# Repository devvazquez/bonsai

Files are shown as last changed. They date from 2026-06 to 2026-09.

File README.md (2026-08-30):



The main repository containing all the files involved in the creation of this smart device, such as cad files, code, designs...

## Motivation for the project
I've always wanted to do a hardware project like this, involving a camera. And I love the idea of being able to connect AI with real-world data, so this project is perfect!

## Repository Structure

```
Bonsai-Glasses/
├── bom.csv             # The bill of materials with links.
├── src/
│   ├── firmware/       # Embedded / microcontroller source code
├── hardware/
│   ├── cad/            # 3D CAD models and mechanical designs
│   └── bonsai_pcb/     # PCB schematics and board layouts
└── assets/             # Images, logos, and other design assets
```

## How it works (WIP)
Thanks to the [backend](https://github.com/devvazquez/bonsai-backend), Bonsai is able to interact easily with **free and fast** AI providers, such as Groq (for the STT and vision LLM). For TTS, it uses Piper (locally), which is esential for **Catalan** support. 
Thanks to the board, a XIAO ESP32 Sense, we can use the provided camera to give the model visual context, which is then used to describe the current enviroment.
Using the built-in web server in the firmware, you can configre all the Wifi networks, and default user button actions. You can also change parameters such as default language. Some of these parameters can also be configured using the wake word (ex. "Hey Bonsai, change the language to Spanish"). 

## Flashing a board
The [web flasher](https://devvazquez.github.io/bonsai/) writes a firmware release to a board over USB from the browser, with no toolchain to install. Plug the board in, pick a version and press write. It needs Chrome, Edge or Opera on a computer, since it runs on the Web Serial API.

Releases are cut by hand: run the **Build and publish firmware** workflow from the Actions tab, give it a version like `v1.0.0`, and it builds the firmware, tags the commit and publishes the release the page reads (`.github/workflows/release.yml`). The page itself lives in [`docs/`](docs/) and is described in [`docs/README.md`](docs/README.md).

Your settings are safe across a flash: `/config.json`, the saved networks and the voice clips are on the SD card, and only the firmware images get replaced.

## Bill of Materials
| Name | Purpose | Quantity | Total Cost (USD) | Link | Distributor |
| --- | --- | --- | --- | --- | --- |
| 3.7V Lipo Battery | Powering the device. | | $10.50 | [Buy](https://www.aliexpress.us/item/3256808990377891.html) | Aliexpress |
| JST PH 2.0 Connector | Connect battery to PCB (Bent pin socket, 2P) | | $1.95 | [Buy](https://www.aliexpress.us/item/3256807255498839.html) | Aliexpress |
| Seeed Studio XIAO ESP32S3 Sense | Tiny devboard with camera support (ESP32S3 Sense Module) | | $20.00 | [Buy](https://es.aliexpress.com/item/1005005544221475.html) | Aliexpress |
| MAX98357A I2S Audio Amplifier | Drives the speakers since ESP32 lacks enough power directly | | $1.68 | [Buy](https://www.aliexpress.us/item/3256812158409627.html) | Aliexpress |
| 75MM OV3660 120° Camera | Captures image for ESP32 to process (120 Degrees GOOD) | | $6.89 | [Buy](https://es.aliexpress.com/item/1005009339247009.html) | Aliexpress |
| Push Button | Taking the photo | | 2.95$ | [Buy](https://www.aliexpress.us/item/3256804762387991.html) | Aliexpress |
| Small Speaker | Playing the TTS sound | | 4.53$ | [Buy](https://www.aliexpress.us/item/3256811556916339.html) | Aliexpress |
| PCB | Holding all the components together | | 23$ | [Buy](https://jlcpcb.com/) | JLPCB |

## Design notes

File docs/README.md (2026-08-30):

# The flashing page

`docs/` is the site published at <https://devvazquez.github.io/bonsai/>. It
writes a firmware release to a board over USB from the browser, using the Web
Serial API and [esptool-js](https://github.com/espressif/esptool-js) (vendored
under `vendor/esptool-js/`, version in `vendor/esptool-js/VERSION`).

Nothing runs on a server: the release assets are fetched from GitHub by the
browser and pushed straight down the serial port.

## Design

The page borrows its tokens and components from the firmware's own setup portal
(`src/firmware/bonsai-firmware/bonsai-setup.html`): the same off-white ground,
the same step rail, buttons, summary rows and status tints, and the same logo
asset. Flashing a board and setting it up afterwards should not look like two
different products, so when that page's palette changes, `styles.css` follows
it.

## Where the images go

`.github/workflows/release.yml` attaches a `manifest.json` to every release it
publishes and the page reads it, so the offsets come from the build rather than
from guessing. That workflow only runs when someone starts it from the Actions
tab with a version number, so tags and pushes never publish a release on their
own.
Releases assembled some other way still work; the page falls back to, in order:

1. **`manifest.json`** in the [ESP Web Tools](https://esphome.github.io/esp-web-tools/)
   shape. Paths resolve against the release's download URL, so plain file names
   are enough.
2. **A merged image**, one asset whose name contains `merged`, `combined`,
   `factory` or `full`, written at `0x0`.
3. **The PlatformIO set**: `bootloader.bin` (`0x0`), `partitions.bin`
   (`0x8000`), `boot_app0.bin` (`0xe000`), `firmware.bin` (`0x10000`).

Whichever route is taken, the page lists every image and its offset before it
writes anything.

Draft releases are hidden. Pre-releases are listed and marked, and the newest
stable release is the one preselected.

## What flashing does not touch

The board keeps its settings. `/config.json`, the Wi-Fi list and the voice clips
live on the SD card, and nothing here writes to the card. Only the firmware
images are replaced, so a board that was already set up comes back on the
network by itself.

## Enabling the site

The workflow in `.github/workflows/pages.yml` publishes this directory on every
push to `main`, but Pages has to be switched on once by a person: **Settings,
Pages, Build and deployment, Source: GitHub Actions**. The workflow cannot do
it for you, since its token is not allowed to create the site. Until that
setting is flipped the deploy job fails at `configure-pages`; re-run it
afterwards and the site goes up.

## Local preview

Web Serial needs a secure context, which `localhost` counts as:

```sh
python3 -m http.server -d docs 8000   # then open http://localhost:8000
```

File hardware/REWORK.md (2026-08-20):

# Board rework: the microSD bus

The XIAO ESP32-S3 **Sense** puts its microSD slot on the same pads the header
brings out, and the first Bonsai board hands two of them to something else:

| Net | U1 pad | GPIO | XIAO alias | Also used by the microSD as |
| --- | --- | ---- | --- | --- |
| `BT1` (SW1 pad 1) | 11 | GPIO9 | D10 | **MOSI** |
| `SD` (U2 pad 4, MAX98357A shutdown) | 10 | GPIO8 | D9 | **MISO** |

The slot's other two lines are SCK on GPIO7 (D8) and CS on GPIO21, which nothing
else touches.

## What it looked like

Flash the board, configure the WiFi over the AP, reboot — and every operation on
the card fails. `SD.begin()` itself succeeds, because at that point nothing has
touched the bus yet; `Audio::begin()` ran next and drove GPIO8 low to hold the
amplifier off. From there `/config.json` cannot be read or written, `/audio`
cannot be created, and the credentials entered over the AP are lost on every
boot, so each one looks like the first.

## The fix

**Firmware — ownership of GPIO8, not its level.** `SPI.begin()` routes that pad
to the SPI peripheral's MISO input. Any `pinMode()` on it points it back at
plain GPIO and the peripheral is left reading a disconnected input — and that is
true of `INPUT` and `INPUT_PULLUP` exactly as much as of `OUTPUT`. The card
still mounts, because identification is short and forgiving, and then every
transfer comes back empty. So nothing outside `playWav()` touches the pin, and
`playWav()` only takes it once the clip is in PSRAM and the file is closed,
then hands it straight back with `spiAttachMISO()`.

Between clips the pin stays with the SPI peripheral and `SD_MODE` is held at
ground by its own internal 100k pull-down, which shuts the amplifier down for
free. That works because this is the bare MAX98357A and not a breakout, whose
100k to VDD would instead have left it on.

**No second rework is needed, and no pull-up.** Two things that look like the
cause here are not:

- *The 100k pull-down on `SD_MODE` dragging MISO down.* It does sit on the net,
  and the arithmetic is unflattering — against the chip's ~45k internal pull-up
  it divides to 2.28 V, under the 2.475 V an ESP32-S3 wants for a HIGH. It still
  is not the fault: with the pin left alone the bus runs fine at full speed.
  Adding a 10k to 3V3 on D9 fixes nothing that is broken.
- *The bus clock being too fast.* A card that mounts and then fails every
  transfer is the classic picture of an over-fast clock, because mounting
  happens at the 400 kHz the spec mandates for identification. Dropping to
  400 kHz changes nothing here; the board reads and writes happily at 4 MHz.

**PCB — the button.** Cut the `BT1` trace between SW1 pad 1 and U1 pad 11
(GPIO9/MOSI) and run a wire from SW1 pad 1 to **U1 pad 4 — GPIO4, D3**, the
nearest pad nothing else claims. SW1 pad 2 already goes to GND, so the switch
stays active-low against the internal pull-up and `BUTTON_PIN` is 4.

Do the cut on the U1 side of SW1 pad 1 so the pad keeps its own copper, and
check continuity between SW1 pad 1 and U1 pad 11 afterwards — it should read
open.

## Pads still free on the header

D4 (GPIO5/SDA), D5 (GPIO6/SCL), D6 (GPIO43/TX), D7 (GPIO44/RX).

## For the next revision

Route `BT1` to GPIO4 in the schematic so the board needs no rework. Giving the
amplifier's `SD` net its own free pad — D4 (GPIO5) — would also let the firmware
stream a clip straight off the card again instead of buffering it into PSRAM
first, and would drop the `spiAttachMISO()` dance in `Audio::ampRelease()`
along with the standing risk that some future code path calls `pinMode()` on
GPIO8 and quietly breaks the card all over again.

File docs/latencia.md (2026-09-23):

# Latencia: qué se puede hacer con la cola de Groq

Groq responde rapidísimo, pero el tiempo hasta el primer token varía mucho: la
misma petición pasa de ~1 s a ~4 s sin que cambie nada del lado del dispositivo.
Eso es tiempo de planificación en la infraestructura de Groq — no se acorta desde
fuera. Solo hay tres ataques reales, y son complementarios.

## 1. Taparla (firmware)

El clip `start_talking` ya existe y se descarga al arrancar. Reproducirlo nada
más disparar la foto, mientras la petición está en vuelo, hace que el usuario
oiga algo a los ~200 ms **siempre**. Un "digue'm" de 1,5 s se come entera la cola
mediana y buena parte de la mala.

No reduce la latencia; elimina la percepción de latencia, que es lo que importa
cuando llevas las gafas puestas.

Detalle de implementación: `playWav()` coge GPIO8 (que es el MISO de la tarjeta)
y la tarjeta entera durante todo el clip, así que hay que ordenarlo con el
escritor de fotos en segundo plano y con `beginStream()` de la respuesta. La
forma que funciona es una tarea aparte que toma `sdLock`, carga el clip a PSRAM y
lo reproduce, mientras el hilo principal sube la imagen por el socket.

*Implementado en el flujo de `/ask`.*

## 2. Petición cubierta / hedging (backend)

En `bonsai-backend`: lanzar la llamada de visión y, si a los ~800 ms no ha
contestado, lanzar una segunda idéntica y quedarse con la que llegue antes,
cancelando la otra.

La cola es aleatoria por petición, así que dos tiradas independientes convierten
el p95 en algo parecido al p50. Se pagan tokens dobles solo en la cola lenta
(~10-20 % de las veces), y con el plan gratuito de Groq eso cuenta: ver el
apartado «Cuota de Groq» en el CLAUDE.md del backend antes de activarlo.

Variante más agresiva: lanzar en paralelo a dos proveedores distintos (Groq +
Cerebras, por ejemplo) y tomar el primero que conteste. Ahí el coste extra no es
de la misma cuota.

*Pendiente.*

## 3. Recortar lo que sí se controla

- **El cuerpo de `/look` va en base64 dentro de JSON**: son 33 % de bytes de más
  subiendo por un enlace de ~23 KB/s. `/ask` ya manda el JPEG binario
  (`[4 bytes de longitud][foto][audio]`), así que esta ya está ganada en el
  camino nuevo; `/look` sigue pagándola.
- **Bajar resolución/calidad de captura**: reduce subida *y* prefill. El backend
  ya reduce a 896 px antes de llamar a Groq (una foto de 3,1 MB son ~50.000
  tokens; a 896 px son 2.656), pero lo que sube el dispositivo lo paga el
  dispositivo.
- **Limitar la respuesta a 1-2 frases**: menos tokens generados y, como el TTS
  sale por frases, la primera se oye antes.
- **Handshake TLS caliente**: ya hecho (`warmUp()` al arrancar y `setReuse(true)`),
  vale más de un segundo en este chip.
- **Prebuffer de 400 ms** antes del primer sonido: ya está medido y ajustado al
  enlace real (8 kHz = 16 KB/s contra 21-30 KB/s de red). Ver las notas en
  `Audio.cpp`.

## Lo que ya no hay que volver a medir

- Groq contra Gemini para visión: 552 ms (551-554) contra 844 ms (649-937), y
  sobre todo mucho más regular. Decidido con datos, Gemini fuera.
- Piper contra edge-tts: 205 ms de mediana contra 1.320 ms con texto nuevo.
- La subida de la foto y la espera del backend se miden por separado en los logs
  (`[t] look: ...`), justamente para no confundir el problema de uno con el otro.

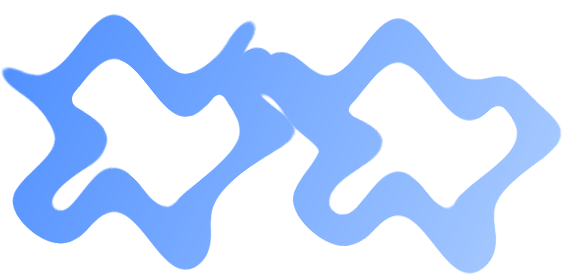
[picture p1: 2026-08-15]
docs/assets/bonsai-mark.png

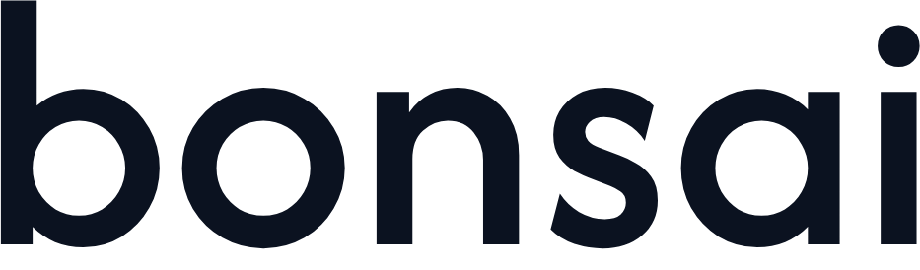
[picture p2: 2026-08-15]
assets/bonsai-wordmark.png

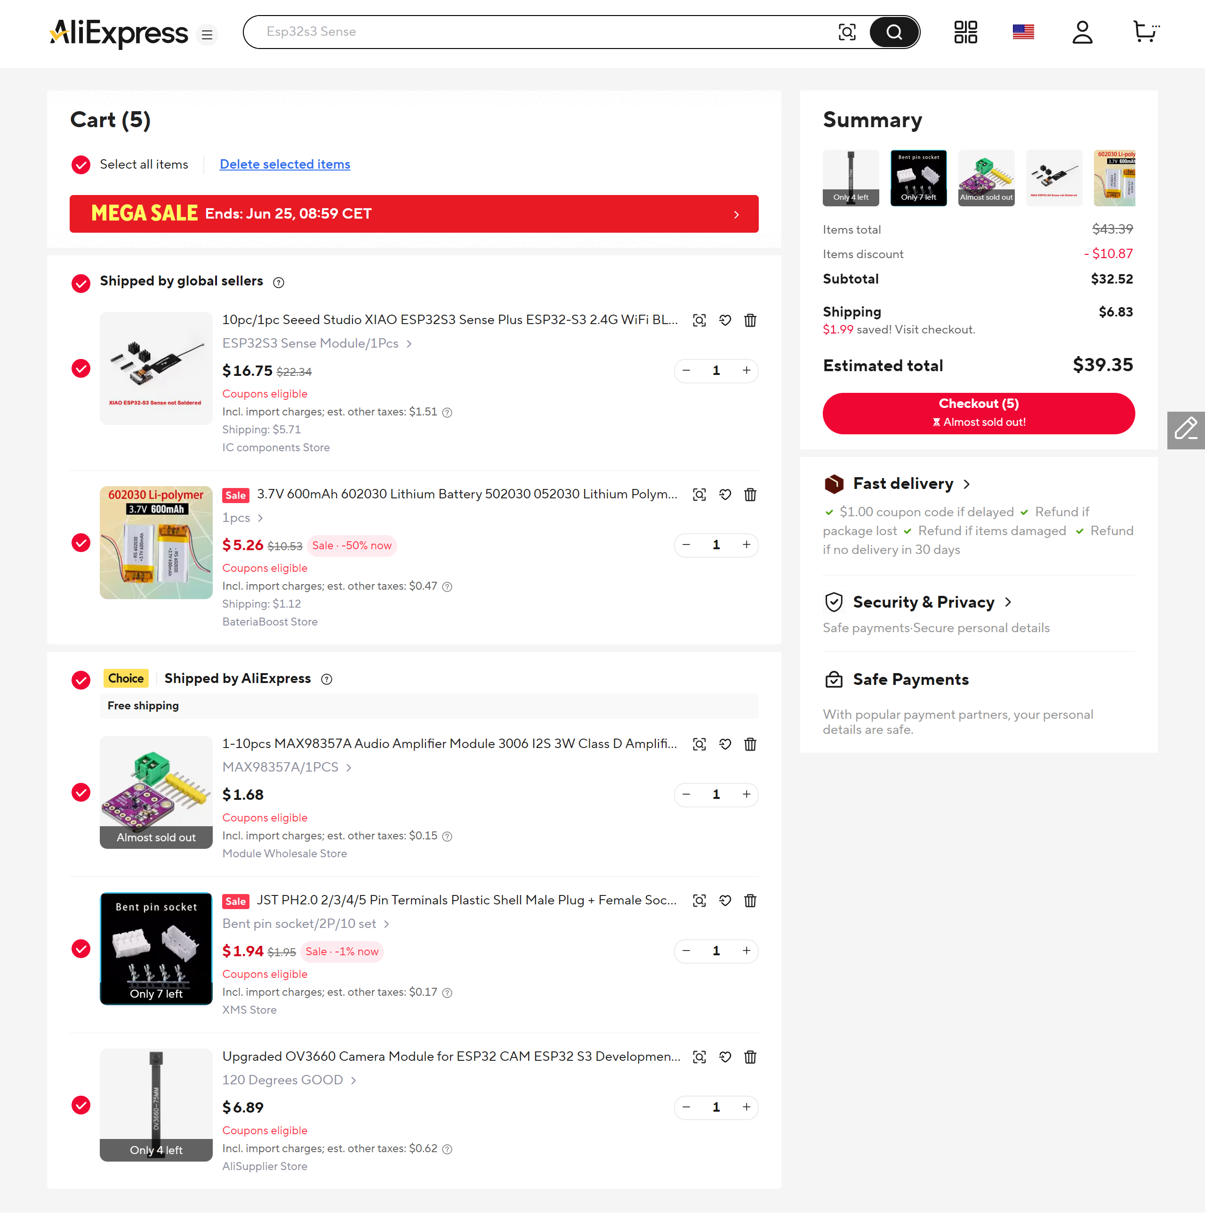
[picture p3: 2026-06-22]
assets/cart-image.png

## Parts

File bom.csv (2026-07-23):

Name | Purpose | Quantity | Total Cost (USD) | Link | Distributor
3.7V Lipo Battery | Powering the device. |  | 10.50 | https://www.aliexpress.us/item/3256808990377891.html | Aliexpress
JST PH 2.0 Connector | Connect battery to PCB (Bent pin socket, 2P) |  | 1.95 | https://www.aliexpress.us/item/3256807255498839.html | Aliexpress
Seeed Studio XIAO ESP32S3 Sense | Tiny devboard with camera support (ESP32S3 Sense Module) |  | 20.00 | https://es.aliexpress.com/item/1005005544221475.html | Aliexpress
MAX98357A I2S Audio Amplifier | Drives the speakers since ESP32 lacks enough power directly |  | 1.68 | https://www.aliexpress.us/item/3256812158409627.html | Aliexpress
75MM OV3660 120° Camera | Captures image for ESP32 to process (120 Degrees GOOD) |  | 6.89 | https://es.aliexpress.com/item/1005009339247009.html | Aliexpress
Push Button | Taking the photo |  | 2.95 | https://www.aliexpress.us/item/3256804762387991.html | Aliexpress
Small Speaker | Playing the TTS sound |  | 4.53 | https://www.aliexpress.us/item/3256811556916339.html | Aliexpress

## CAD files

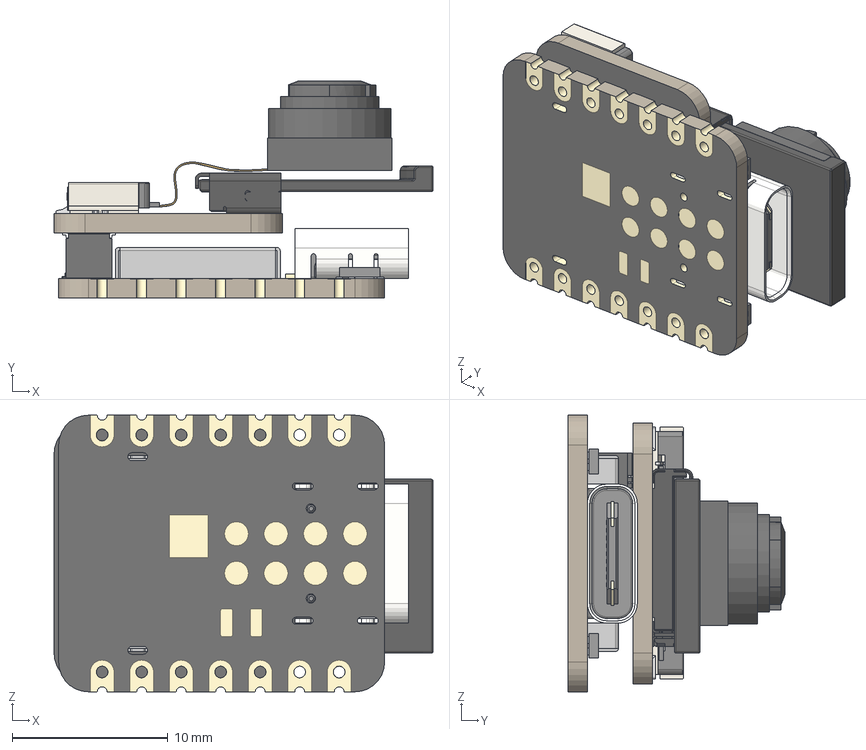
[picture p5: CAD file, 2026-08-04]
hardware/bonsai_pcb/assets/Seeed Studio XIAO-ESP32-S3-Sense.step
24.4 x 14.0 x 17.8 mm
BOSS-EXTRUDE14_8_
BOSS-EXTRUDE7_4_
BOSS-EXTRUDE7_3_
BOSS-EXTRUDE14_4_
BOSS-EXTRUDE14_2_
BOSS-EXTRUDE14_11_
BOSS-EXTRUDE7_7_
BOSS-EXTRUDE14_9_
BOSS-EXTRUDE14_3_
BOSS-EXTRUDE14_7_
MIRROR2
BOSS-EXTRUDE14_5_
BOSS-EXTRUDE14_12_
BOSS-EXTRUDE7_8_
BOSS-EXTRUDE7_1_
BOSS-EXTRUDE14_10_
BOSS-EXTRUDE7_9_
BOSS-EXTRUDE14_6_
BOSS-EXTRUDE14_1_
BOSS-EXTRUDE7_6_
BOSS-EXTRUDE7_2_
CUT-EXTRUDE5
BOSS-EXTRUDE7_5_
Shield
Pins x 2
U.FL-R-SMT-1_10_ v1
DF40C-30DP-0.4V_51_ v1
DF40HC(3.0)-30DS
10067099-200LF v1
PCB
MicroSD v2
JUSHUO AFC01-S24FCA-00
Camer Module

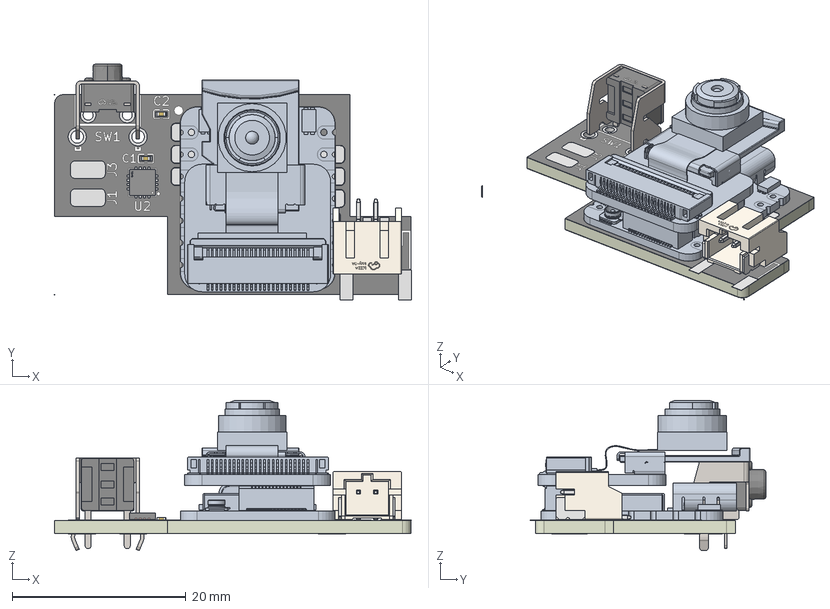
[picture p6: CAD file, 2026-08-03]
hardware/bonsai_pcb/pcb.step
41.1 x 27.1 x 17.3 mm
CONN-SMD_P2.00_S2B-PH-SM4-TB-LF-SN
TQFN-16_L3.0-W3.0-P0.50-BL-EP1.5
C0402_L1.0-W0.5-H0.5 x 2
SW-TH_TS-1102N-5516
Seeed Studio XIAO-ESP32-S3-Sense
bonsai_pcb_copper
bonsai_pcb_pad
bonsai_pcb_via
bonsai_pcb_silkscreen x 2
bonsai_pcb_soldermask x 2
bonsai_pcb_PCB_1
bonsai_pcb_PCB_2
bonsai_pcb_PCB_3
bonsai_pcb_PCB_4

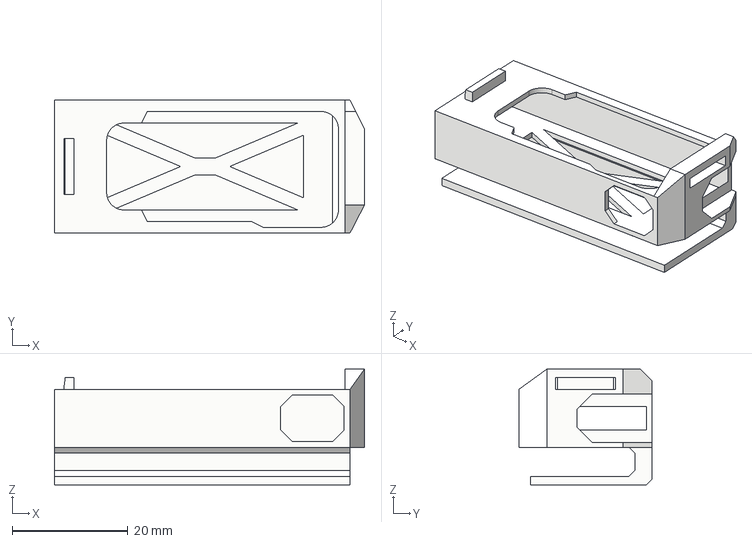
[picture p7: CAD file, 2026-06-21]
hardware/cad/Bonsai_Case_V1.step
53.5 x 23.0 x 20.0 mm

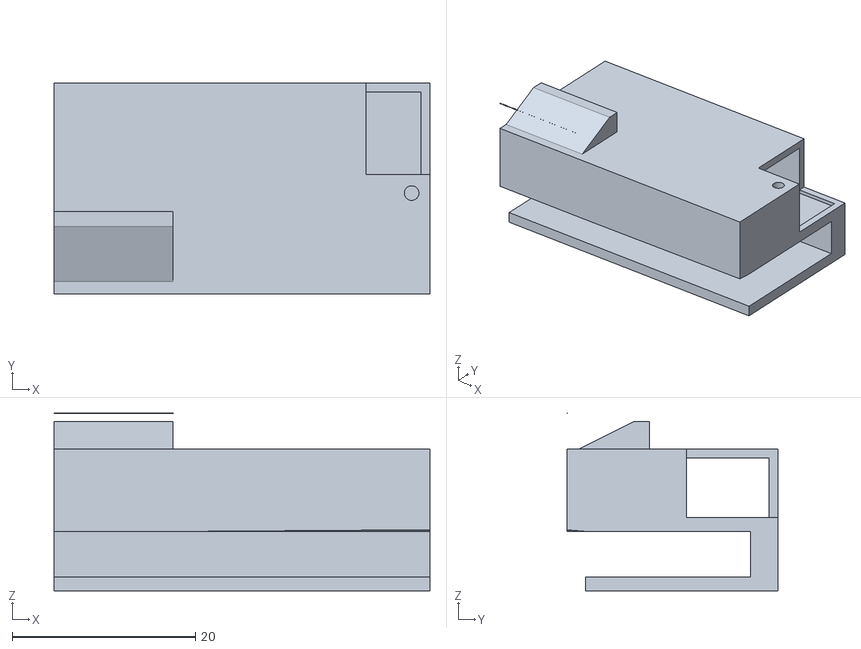
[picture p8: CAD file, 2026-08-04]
hardware/bonsai_pcb/assets/Bonsai Case V2.stl
41.0 x 23.0 x 19.4

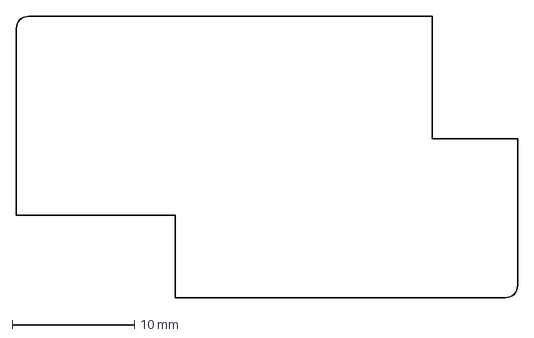
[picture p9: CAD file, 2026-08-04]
hardware/bonsai_pcb/assets/Bonsai PCB Outline V2.dxf
41.0 x 23.0 mm

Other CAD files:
hardware/cad/Bonsai Case V1.stl

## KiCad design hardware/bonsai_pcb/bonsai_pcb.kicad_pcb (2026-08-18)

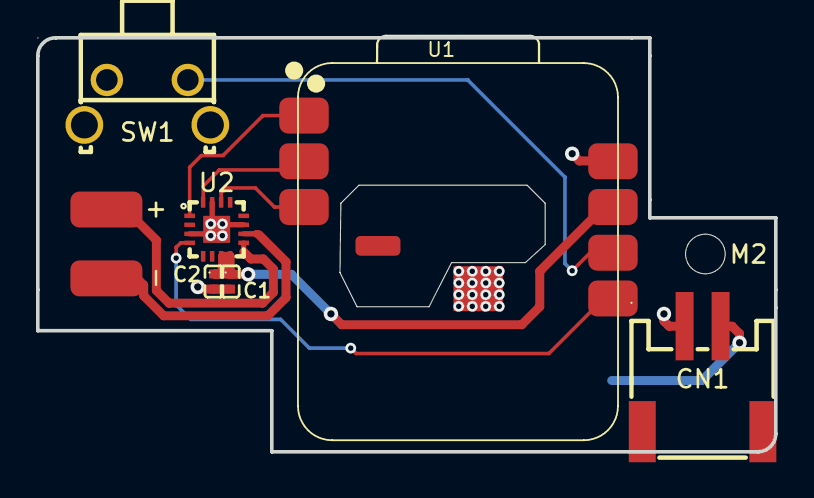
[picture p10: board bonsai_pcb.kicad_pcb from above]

Board: 2 copper layers, 41.0 x 23.0 mm, 10 parts (1 on the bottom side), 10 nets.

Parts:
+: Conn_01x01_Socket; SolderWirePad_1x01_SMD_2x4mm
-: Conn_01x01_Socket; SolderWirePad_1x01_SMD_2x4mm
C1: 10uF; C0402
C2: 100nF; C0402
CN1: S2B-PH-SM4-TB; CONN-SMD_P2.00_S2B-PH-SM4-TB-LF-SN
J1: B+ Solder Pad; SolderWirePad_1x01_SMD_2x4mm
M2: MountingHole_2.2mm_M2
SW1: TS-1102N-5516; SW-TH_TS-1102N-5516
U1: XIAO-ESP32-S3-SMD
U2: MAX98357AETE+T; TQFN-16_L3.0-W3.0-P0.50-BL-EP1.5

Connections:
/BAT +: CN1.2, J1.1 (Pin_1_1)
/OUTN: -.1 (Pin_1_1), U2.10 (OUTN)
/OUTP: +.1 (Pin_1_1), U2.9 (OUTP)
BLCK: U1.2 (GPIO2_A1_D1), U2.16 (BCLK)
BT1: SW1.1, U1.11 (GPIO9_A10_D10_MOSI)
DIN: U1.1 (GPIO1_A0_D0), U2.1 (DIN)
GND: C1.2, C2.2, CN1.1, SW1.2, U1.13 (GND), U1.25 (GPIO40_MTDO), U2.3 (GND), U2.11 (GND), U2.15 (GND), U2.17 (EP)
LRC: U1.3 (GPIO3_A2_D2), U2.14 (LRCLK)
SD: U1.10 (GPIO8_A9_D9_MISO), U2.4 (~SD_MODE)
VIN: C1.1, C2.1, U1.12 (3V3), U2.7 (VDD), U2.8 (VDD)

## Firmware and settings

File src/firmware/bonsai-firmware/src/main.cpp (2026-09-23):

#include <Arduino.h>
#include <Camera.h>
#include <SD.h>
#include <SPI.h>
#include <WiFiManager.h>
#include <Audio.h>
#include <ArduinoJson.h>
#include <Lang.h>
#include <SetupPortal.h>
#include <Mic.h>
#include <freertos/stream_buffer.h>
#include <esp_timer.h>

// The Arduino loop task gets 8 KB by default, and that is not enough for what
// runs nested inside look(): HTTPClient, mbedTLS and the audio sink all stack
// up in the same frame. It showed up as a stack canary panic in loopTask on the
// first /look after the streaming rewrite, not as anything that looked like
// memory at all. 16 KB leaves real headroom.
SET_LOOP_TASK_STACK_SIZE(16 * 1024);

// The tactile switch (SW1). The first board wired it to U1 pad 11 — GPIO9,
// which is D10 = MOSI of the microSD bus — so holding the button shorted MOSI
// to ground and a pull-up on it fought the card. That trace is cut and the
// switch leg goes to U1 pad 4 = GPIO4 = D3 instead, the nearest free pad.
// See hardware/REWORK.md.
#define BUTTON_PIN 4

// microSD slot on the Sense expansion board: the default SPI pins (SCK 7,
// MISO 8, MOSI 9) with CS on GPIO21. Not the variant's default SS, which is
// GPIO44 — the RX pad — and is what a bare SD.begin() would drive instead,
// so the card would never mount.
constexpr int kSdCs = 21;

// Bus speeds to try, fastest first. The first one normally takes it; the slower
// entries only matter for a marginal card or a board that has been reworked.
//
// Worth knowing before touching this list: bus speed was never what broke this
// board. A card that mounts and then fails every transfer looks exactly like a
// clock that is too fast, and it is not — mounting happens at the 400 kHz the
// spec mandates for identification, so a card can report its type and size
// correctly while nothing else works. Chasing that costs a lot of flash cycles.
// See the note on kAmpEnable in Audio.h for what the real cause was.
constexpr uint32_t kSdFrequencies[] = {4000000, 1000000, 400000};

constexpr const char* kSdProbeFile = "/.bonsai-probe";

/* TODO: 
    - Implement backend API.
    - Download TTS defaults. X
    - Groq tools:
        - Stop searching for wifi.
        - Change language.
    -  Config:
        - wifi networks (ssid, password) X
*/


Camera      camera;
WiFiManager wifi;
Audio       audio;
Mic         mic;
SetupPortal portal;

namespace {

// Raised when the board has no network: either WiFiManager gave up on its
// retries, or something asked for the network and found nothing there. Only ever
// a flag. It is set from inside a request — possibly with the audio sink
// mid-stream and the card lock held — so the clip and the portal are run from
// loop(), and from one place, which is what stops the clip playing twice.
volatile bool offlineRequested = false;

constexpr const char* kConfigFile        = "/config.json";
constexpr const char* kLookFile          = "/look.wav";
constexpr const char* kDefaultLang       = "ca-ES";
constexpr const char* kDefaultBackendUrl = "";

// 8 KB and not 4: the setup portal adds the token and up to five
// ssid/password pairs on top of everything else that lives in here.
DynamicJsonDocument configDoc(8192);
bool                isFirstBoot = false;

// Mounts the card at the fastest speed it will actually work at.
//
// A successful mount is not enough to go on: it only proves the card answered
// during the 400 kHz init, not that it will answer at the bus speed that
// follows. So every candidate has to write a byte and read it back before it is
// accepted, which is the part that was failing before.
bool mountSd() {
    bool mounted = false;

    for (const uint32_t hz : kSdFrequencies) {
        // Only ever unmount something that mounted: SD.end() on a card that
        // never came up leaves the driver in a state the next begin() will not
        // recover from, which costs every remaining candidate.
        if (mounted) {
            SD.end();
            mounted = false;
        }

        if (!SD.begin(kSdCs, SPI, hz)) {
            Serial.printf("SD: no mount at %u kHz.\n", hz / 1000);
            continue;
        }
        mounted = true;

        bool ok = false;
        File probe = SD.open(kSdProbeFile, FILE_WRITE);
        if (probe) {
            const uint8_t written = probe.write('B');
            probe.close();

            // Read it back: a write that reports success but lands nowhere is
            // the failure mode this whole exercise is about.
            File verify = SD.open(kSdProbeFile, FILE_READ);
            if (written == 1 && verify) {
                ok = verify.read() == 'B';
                verify.close();
            }
            SD.remove(kSdProbeFile);
        }

        if (!ok) {
            Serial.printf("SD: mounted at %u kHz but cannot write; slowing down.\n",
                          hz / 1000);
            continue;
        }

        const uint8_t type = SD.cardType();
        const char*   name = type == CARD_NONE ? "none" :
                             type == CARD_MMC  ? "MMC"  :
                             type == CARD_SD   ? "SDSC" :
                             type == CARD_SDHC ? "SDHC" : "unknown";
        Serial.printf("SD: %s, %llu MB, read/write at %u kHz.\n",
                      name, SD.cardSize() >> 20, hz / 1000);
        return true;
    }

    if (mounted) SD.end();
    return false;
}

void applyConfigDefaults() {
    if (!configDoc.containsKey("lang"))        configDoc["lang"]        = kDefaultLang;
    if (!configDoc.containsKey("backend_url")) configDoc["backend_url"] = kDefaultBackendUrl;
}

// Load /config.json from the SD card.
// Sets isFirstBoot when the file is missing or unreadable, so callers can run first-time setup.
void loadConfig() {
    if (!SD.exists(kConfigFile)) {
        isFirstBoot = true;
        applyConfigDefaults();
        return;
    }

    File file = SD.open(kConfigFile, FILE_READ);
    if (!file) {
        isFirstBoot = true;
        applyConfigDefaults();
        return;
    }

    String content = file.readString();
    file.close();

    if (deserializeJson(configDoc, content) != DeserializationError::Ok) {
        isFirstBoot = true;
        configDoc.clear();
    }

    applyConfigDefaults();
}

void saveConfig() {
    File file = SD.open(kConfigFile, FILE_WRITE);
    if (!file) {
        // Worth saying out loud: silently dropping this is what made a board
        // that could not reach the card look like one stuck on its first boot,
        // asking for the WiFi again every time.
        Serial.printf("Could not open %s for writing: config not saved.\n",
                      kConfigFile);
        return;
    }
    serializeJson(configDoc, file);
    file.close();
}


// ---------------------------------------------------------------------------
// Background photo writer.
//
// Writing the JPEG is pure bookkeeping — nobody is waiting to look at it — so
// it has no business sitting between the button and the spoken answer. A task
// does it instead, and the card lock lets it slot into the seconds this board
// spends waiting for the backend, rather than merely being pushed to the end.
//
// The lock is not optional. During playback the amplifier owns GPIO8, which is
// the card's MISO (see Audio.h), so the card is unusable for the whole clip; a
// write landing there would fail and could leave the filesystem mid-update.
// ---------------------------------------------------------------------------

constexpr const char* kPhotoDir = "/photos";

struct PhotoJob {
    uint8_t* buf;
    size_t   len;
};

SemaphoreHandle_t sdLock     = nullptr;
QueueHandle_t     photoQueue = nullptr;

// Counted once, so numbering carries on across reboots instead of overwriting.
uint32_t countPhotos() {
    uint32_t n = 0;
    File dir = SD.open(kPhotoDir);
    if (dir) {
        for (File f = dir.openNextFile(); f; f = dir.openNextFile()) { ++n; f.close(); }
        dir.close();
    }
    return n;
}

void photoTask(void*) {
    uint32_t index   = 0;
    bool     counted = false;

    for (;;) {
        PhotoJob job;
        if (xQueueReceive(photoQueue, &job, portMAX_DELAY) != pdTRUE) continue;

        const uint32_t tQueued = millis();
        xSemaphoreTakeRecursive(sdLock, portMAX_DELAY);
        const uint32_t tStart = millis();

        if (!SD.exists(kPhotoDir)) SD.mkdir(kPhotoDir);
        if (!counted) { index = countPhotos(); counted = true; }

        char path[48];
        snprintf(path, sizeof(path), "%s/%05u.jpg", kPhotoDir, index);

        bool ok = false;
        File f = SD.open(path, FILE_WRITE);
        if (f) {
            ok = f.write(job.buf, job.len) == job.len;
            f.close();
        }
        xSemaphoreGiveRecursive(sdLock);

        if (ok) {
            ++index;
            Serial.printf("  [t] photo %s: %u KB, waited %u ms for the card, "
                          "wrote in %u ms (off the critical path)\n",
                          path, (unsigned)(job.len / 1024),
                          tStart - tQueued, millis() - tStart);
        } else {
            Serial.printf("photo: could not write %s\n", path);
        }
        heap_caps_free(job.buf);
    }
}

// Copies the frame and hands it over. The copy is needed because the camera has
// only kFrameBuffers buffers and wants this one back immediately.
void savePhotoInBackground(const uint8_t* jpeg, size_t len) {
    if (!photoQueue) return;

    uint8_t* copy = (uint8_t*)heap_caps_malloc(len, MALLOC_CAP_SPIRAM);
    if (!copy) {
        Serial.println("photo: no PSRAM for a copy, not saving this one");
        return;
    }
    memcpy(copy, jpeg, len);

    PhotoJob job{copy, len};
    if (xQueueSend(photoQueue, &job, 0) != pdTRUE) {
        Serial.println("photo: the writer is still busy, dropping this one");
        heap_caps_free(copy);
    }
}

// What a single button press does: photograph whatever is in front of the
// wearer, send it to /look, and say the answer out loud.
//
// The reply is written to the card rather than held in RAM. It is a whole
// spoken sentence, so it is the same few-hundred-KB that broke the clip
// downloads, and playWav() wants a file anyway.
void look() {
    if (!wifi.isConnected()) {
        // No clip and no portal from here: this runs inside loop()'s call, and
        // doing both from the same place the request came from is what played
        // the clip twice. Raise the flag and let loop() handle it once, the same
        // way it handles the retries running out.
        Serial.println("look: no WiFi.");
        offlineRequested = true;
        return;
    }
    if (String(configDoc["backend_url"] | "").length() == 0) {
        Serial.println("look: backend_url is not set - send \"backend <url>\".");
        audio.playDefault(DefaultAudios::MISSING_CONFIG);
        return;
    }

    const uint32_t tAll = millis();

    // The camera throws away kFrameBuffers frames before keeping one, so this
    // is several frame times, not one — and at UXGA a frame is not cheap.
    const uint32_t tCap = millis();
    camera_fb_t* fb = camera.capture();
    const uint32_t capMs = millis() - tCap;
    if (!fb) {
        Serial.println("look: the camera returned no frame.");
        return;
    }
    Serial.printf("  [t] capture: %u ms for %u KB\n",
                  capMs, (unsigned)(fb->len / 1024));

    // Queued, not written: the card write happens on the other task while the
    // backend is thinking.
    savePhotoInBackground(fb->buf, fb->len);

    // Straight from the socket to the amplifier. No file, no second pass over
    // the card, and the first word is spoken while the rest of the sentence is
    // still being generated — the card round trip used to add the whole
    // download plus a re-read before any sound came out at all.
    String   spoken;
    uint32_t firstSampleMs = 0;
    bool     started       = false;

    WiFiManager::AudioSink sink;
    sink.onStart = [&](uint32_t rate) {
        firstSampleMs = millis() - tAll;
        started       = true;
        Serial.printf("  [t] first sample at %u ms, %u Hz\n", firstSampleMs,
                      rate ? rate : 16000u);
        return audio.beginStream(rate);
    };
    sink.onChunk = [&](const uint8_t* pcm, size_t len) {
        audio.writeStream(pcm, len);
        return true;
    };

    const uint32_t tReq = millis();
    const bool ok = wifi.lookStreaming(fb->buf, fb->len, sink, &spoken);
    if (started) audio.endStream();   // owed unconditionally: it holds GPIO8
    const uint32_t reqMs = millis() - tReq;

    camera.release(fb);

    if (!ok) {
        Serial.println("look: nothing was spoken.");
        // Something has to come out of the speaker. From the outside, a backend
        // that answered 502 and a board that died look exactly the same: the
        // button was pressed and nothing happened. Synthesised rather than a
        // clip, because the moment the backend is unreachable is the moment a
        // clip that was never downloaded cannot be fetched either.
        audio.beep(392, 140);
        return;
    }

    // "to answer" is the number that matters: button pressed to first sound.
    Serial.printf("  [t] TOTAL %u ms = capture %u + speak %u   (to answer: %u ms)\n",
                  millis() - tAll, capMs, reqMs, firstSampleMs);
}

// ---------------------------------------------------------------------------
// The "tell me" clip, played on its own task.
//
// It has to overlap the photo upload, and playing it is blocking by nature: the
// clip is pulled into PSRAM and then pushed at the I2S DMA in real time. So it
// goes on a task of its own while the loop task writes the photo to the socket.
//
// It takes the card lock for the whole clip and not only for the read, because
// the amplifier owns GPIO8 — the card's MISO — while it plays. That is the same
// lock the background photo writer takes, so the two take turns instead of
// corrupting each other. See the note on kAmpEnable in Audio.h.
// ---------------------------------------------------------------------------

TaskHandle_t      clipTask = nullptr;
SemaphoreHandle_t clipDone = nullptr;
volatile DefaultAudios clipWanted = DefaultAudios::START_TALKING;

void clipTaskFn(void*) {
    for (;;) {
        ulTaskNotifyTake(pdTRUE, portMAX_DELAY);

        xSemaphoreTakeRecursive(sdLock, portMAX_DELAY);
        audio.playDefault(clipWanted);
        xSemaphoreGiveRecursive(sdLock);

        xSemaphoreGive(clipDone);
    }
}

// Starts a clip and returns at once. At most one at a time: the amplifier pin
// has one owner.
bool startClip(DefaultAudios which) {
    if (!clipTask || !clipDone) return false;
    if (audio.isPlaying()) return false;

    // Any leftover completion from a clip nobody waited for.
    xSemaphoreTake(clipDone, 0);
    clipWanted = which;
    xTaskNotifyGive(clipTask);
    return true;
}

// Waits for the clip to finish. The recording cannot start before it does: the
// mic and the amplifier share the I2S controller, and a mic opened early would
// record the glasses talking to themselves.
void waitClip(uint32_t timeoutMs) {
    if (!clipDone) return;
    if (xSemaphoreTake(clipDone, pdMS_TO_TICKS(timeoutMs)) != pdTRUE) {
        Serial.println("clip: still playing, carrying on without it");
    }
}

// ---------------------------------------------------------------------------
// The question, recorded on its own task.
//
// The mic used to be opened by the HTTP code, when it asked for the first
// bytes of audio — that is, only once the photo had finished uploading. With
// the clip now starting on the button press, a slow upload would leave a gap
// between "tell me" ending and the mic opening, and whatever the wearer said
// in it was lost. So recording starts the moment the clip ends, whatever the
// network is doing, and the voiced audio queues in PSRAM until the request is
// ready to take it.
// ---------------------------------------------------------------------------

struct Recording {
    // 16 s at 16 kHz PCM16: the gate's 15 s ceiling plus the pre-roll. In PSRAM,
    // where half a megabyte is nothing.
    static constexpr size_t kBytes = 16 * kMicRate * 2;

    StreamBufferHandle_t stream  = nullptr;
    StaticStreamBuffer_t streamStruct;
    uint8_t*             storage = nullptr;
    SemaphoreHandle_t    finished = nullptr;
    VoiceGate            gate;
    uint32_t             gain       = 4;
    bool                 clipGoing  = false;

    volatile bool abort        = false;
    volatile bool done         = false;
    volatile bool gaveUp       = false;
    volatile bool heardAny     = false;
    volatile bool clipConsumed = false;
    volatile uint32_t dropped  = 0;
};
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
void loop() {
    // Out of network: say so out loud and put the panel up, so the way to fix
    // it is the same whether the retries ran out or a button press just found
    // there was nothing there. Checked first — this is the board announcing it
    // cannot do its job, and everything below assumes it can.
    if (offlineRequested) {
        offlineRequested = false;
        Serial.println("No network: playing the clip and raising the panel.");
        audio.playDefault(DefaultAudios::NO_WIFI);
        runSetupPortal(SetupPortal::Mode::Panel);
    }

    // Button: debounce, then single / double / long press.
    //
    // Presses are counted on release rather than on the falling edge, which is
    // what makes a long press distinguishable at all: while the button is still
    // down there is no way to know yet whether it is a tap. It costs look() the
    // duration of the press itself — some 80 ms on top of the 250 ms the
    // double-press window already cost — and buys the AP an entry point on a
    // board with no screen and no console.
    static bool     held          = false;
    static uint32_t lastChange    = 0;
    static uint32_t pressStart    = 0;   // falling edge of the press being held
    static uint32_t lastRelease   = 0;   // rising edge, opens the double window
    static uint8_t  pressCount    = 0;
    static bool     waitingDouble = false;
    static bool     longFired     = false;

    const uint32_t DEBOUNCE_MS     = 50;
    const uint32_t DOUBLE_PRESS_MS = 250;
    // 2 s: past anything anyone reaches while tapping, short enough to find
    // without being told.
    const uint32_t LONG_PRESS_MS   = 2000;

    uint32_t now = millis();

    // Drain every edge the ISR recorded, including ones from while the loop was
    // blocked. Timestamps come from the edge, not from now, so a press that is
    // only read about seconds later is still measured correctly.
    BtnEdge e;
    while (btnPop(e)) {
        if (e.down == held) continue;                  // no transition
        if (e.ms - lastChange <= DEBOUNCE_MS) continue; // contact bounce
        lastChange = e.ms;
        held       = e.down;

        if (held) {
            pressStart = e.ms;
            longFired  = false;
            Serial.printf("BUTTON pressed on GPIO%d\n", BUTTON_PIN);
        } else {
            lastRelease = e.ms;
            // A press already consumed by the long-press branch is not a tap.
            if (!longFired) {
                pressCount++;
                waitingDouble = true;
            }
        }
    }

    if (btnDropped) {
        Serial.printf("BUTTON dropped %u edge(s): the loop was away too long\n",
                      (unsigned)btnDropped);
        btnDropped = 0;
    }

    // Fires while the button is still down, so holding it does something
    // observable instead of the user having to guess how long is long enough.
    // Never returns: the portal ends in a reboot.
    if (held && !longFired && now - pressStart >= LONG_PRESS_MS) {
        longFired     = true;
        waitingDouble = false;
        pressCount    = 0;
        Serial.println("BUTTON held: raising the setup access point.");
        // Synthesised rather than a clip: this has to work on a board whose card
        // is empty or missing, which is exactly the board someone reaches for
        // this button on.
        audio.beep(880, 220);
        runSetupPortal(SetupPortal::Mode::Panel);
    }

    if (waitingDouble && now - lastRelease > DOUBLE_PRESS_MS) {
        waitingDouble = false;
        if (pressCount == 1) {
            ask();
        } else if (pressCount >= 2) {
            // Double press: describe what is in front of the wearer without
            // being asked anything. That is /look, which needs no voice and is
            // the fallback when it is too loud to be heard.
            look();
        }
        pressCount = 0;
    }


    wifi.loop();
}

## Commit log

2026-06-20 Rename pcb directory to bonsai_pcb
2026-06-21 Added the first version of the 3d case model.
    [Bonsai_Case_V1.step]
2026-06-21 Update README to include bom.csv description
    Added a description for the bill of materials file.
2026-06-22 Uploaded the bom.csv
    [bom.csv]
2026-06-22 Add Bill of Materials to README
    Added a Bill of Materials section with components, purposes, quantities, costs, and links.
2026-06-29 Started working on the frimware and edited the cad file
    [Bonsai Case V1.stl, pcb.step]
2026-07-13 Add bonsai-web website and KiCad PCB source files
    Exclude node_modules via .gitignore and unignore KiCad project files.
    [bonsai_pcb.kicad_pcb, bonsai_pcb.kicad_sch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]
2026-07-13 Redesign app screens around an enso status ring, mobile-first
    The connection ring is now the app's status language: an open ring is
    idle, a slowly turning ring is searching, and the ring closes when the
    glasses connect. The same motif reads battery level on the dashboard.
    Screens keep the original palette and shadcn components; changes are
    layout-level: single mobile column, CTA moved to the thumb zone,
    staggered section load-in, bigger tap targets, and reduced-motion
    support for all new animation.
2026-07-13 Brush-stroke enso, EN/ES/CA language switch, drop glasses branding
    The ring is now drawn like real ink: three stacked arcs of stepped
    width taper the ends, a tonal gradient runs along the stroke, and a
    turbulence filter roughens the edge. The enso replaces the glasses
    icon as the brand mark everywhere, since the device is a clip-on
    wearable rather than glasses, and copy now says "your Bonsai" instead
    of "your glasses". All interface strings move behind a small i18n
    provider with English, Spanish and Catalan, picked automatically from
    the system locale and switchable from Settings.
2026-07-23 Add Push Button and Small Speaker to components list
2026-07-23 Add PCB component to README
    Added PCB entry to the components list with pricing and link.
2026-07-23 Update PCB and BOM files
    [bom.csv, bonsai_pcb.kicad_pcb, bonsai_pcb.kicad_sch]
2026-07-23 Update PCB outputs and project files
    [bonsai_pcb.kicad_pcb, pcb.step]
2026-08-03 Update PCB, schematic, and STEP model
    [bonsai_pcb.kicad_pcb, bonsai_pcb.kicad_sch, pcb.step]
2026-08-04 Add PCB assets and component library files
    [Bonsai Case V2.stl, Bonsai PCB Outline V2.dxf, Seeed Studio XIAO-ESP32-S3-Sense.step]
2026-08-04 Replace BLE/TTS with Audio lib, update WiFiManager and main firmware
    [main.cpp]
2026-08-07 Play the WAV clips over I2S
    playWav() reads a mono 16-bit PCM WAV off the SD card and writes it to the
    MAX98357A, samples in the LEFT slot and zeroes in the right, which is the
    channel the amplifier picks with SD driven high. begin() installs the driver
    and playDefault() plays a clip in the current language.
    Written against the legacy driver/i2s.h: this project is on arduino-esp32
    2.0.17 (IDF 4.4) and driver/i2s_std.h does not exist there, so the newer
    i2s_channel_* API does not compile.
    Pins come from the schematic (DIN=GPIO1, BCLK=GPIO2, LRC=GPIO3, SD=GPIO8).
    Differences from the draft this came from: chunks are word-aligned so an odd
    size skips its pad byte; the sample rate comes from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
    [main.cpp]
2026-08-08 Add Piper TTS synthetic wake-word generator for hey_bonsai
    Generates 16kHz/mono/PCM16 1000ms clips of "Hey Bonsai" across 7 Piper
    voices (en/es/ca), randomising synthesis params and applying mic-like
    augmentation (noise at 15-25dB SNR, pitch shift, gain jitter) so the
    wake-word model cannot key on TTS artefacts. Includes 300 generated
    samples, metadata and Edge Impulse upload notes.
    [metadata.csv]
2026-08-09 Move to pioarduino so the current I2S API is available
    The official espressif32 platform is at 7.0.1, its latest release, and it
    still pins framework-arduinoespressif32 ~3.20017.0 — Arduino 2.0.17 on
    IDF 4.4. That is why driver/i2s_std.h did not exist and playWav had to be
    written against the legacy driver. Espressif stopped maintaining the
    PlatformIO platform; pioarduino is the community fork that tracks Arduino 3.x.
    Now on Arduino 3.3.11 / IDF 5.5.5, so Audio uses i2s_new_channel,
    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
2026-08-13 Mount the SD card on the right CS pin and fix the default-clip route
    Two bugs that were masking each other: with the card unmounted the clip
    downloads had nowhere to write, so their 404s never showed up.
    SD.begin() with no argument uses the variant's default SS, GPIO44 — the RX
    pad — but the microSD slot on the Sense expansion board is CS 21 on the
    default SPI pins (SCK 7, MISO 8, MOSI 9). The card never mounted, so
    /config.json was never read and every boot looked like the first one. Bind
    the bus explicitly and report a failed mount instead of ignoring it.
    The default clips were requested from /api/v1/clips/{id}, which the backend
    does not serve — the route is /api/v1/audios/{id} (a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
    [main.cpp]
2026-08-13 Teach the camera about the OV3660
    The BOM specifies a 75mm OV3660 module, but the config was the stock
    OV2640 one. Verified on hardware: the sensor reports PID 0x3660 and,
    untouched, produces upside-down frames.
    That last part is why this matters more than it looks. The photo goes to
    a vision model, so an inverted frame comes back as a fluent, confident
    description of an inverted scene. Nothing in the answer looks wrong. The
    vflip is the fix; Espressif's CameraWebServer example carries the same
    block behind the same PID check.
    Also from the bench:
    - fb_count 1 -> 2. With one buffer the OV3660's DMA has nowhere to write
    while the encoder is still on the previous frame, which is the FB-OV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
2026-08-18 Redraw the board with the tactile switch and the logo silkscreen
    Brings in the JLCPCB tactile-switch symbol/footprint/3D model, adds the
    logo footprint on the silkscreen, and reworks the schematic and layout
    around them.
    [bonsai_pcb.kicad_pcb, bonsai_pcb.kicad_sch]
2026-08-19 Keep the amplifier off the microSD's MISO line
    Every SD operation failed from the first reboot after setup: the card
    mounted, then Audio::begin() drove GPIO8 low to hold the amplifier off.
    GPIO8 is D9 — MISO of the bus the Sense board's microSD slot sits on —
    and this net has no resistor, U1 pad 10 runs straight to the MAX98357A's
    SD_MODE on U2 pad 4. A push-pull low there clamps the card's data-out to
    ground, so /config.json could not be read or written and /audio could not
    be created. The credentials entered over the AP were lost on every boot,
    which is why each one asked for the WiFi again.
    The pin is now only driven while nothing is reading the card. Between
    clips it is left as an i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
    [main.cpp]
2026-08-20 Pull MISO up between clips, and say what the card actually is
    The amplifier's SD_MODE carries an internal 100k pull-down and shares the
    net with the card's MISO, so releasing the pin to a bare input left the
    line at 0 V: sdWait() read the card as busy for ever and every transaction
    died with a failed card select, even though the mount had succeeded.
    INPUT_PULLUP is the strongest pull available from the chip, but against
    that 100k it only reaches 3.3 * 100/145 = 2.28 V, under the 2.475 V this
    part needs for a HIGH. So this helps and does not settle it: a 10k to 3V3
    on D9 would put the line at 3.0 V and finish the job.
    A successful mount followed by failing reads is indistinguishable from a
    m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
    [main.cpp]
2026-08-20 Leave GPIO8 with the SPI peripheral and the card works
    The microSD is fixed, and not for the reason the last two commits gave.
    What breaks the bus is not the level GPIO8 is left at but who owns the pad.
    SPI.begin() routes it to the SPI peripheral's MISO input; any pinMode() on
    it points it back at plain GPIO and the peripheral reads a disconnected
    input from then on. OUTPUT does that, and so do INPUT and INPUT_PULLUP.
    The card still mounts, because identification is short and forgiving, and
    every transfer afterwards comes back empty. The original digitalWrite LOW
    was one instance of the general fault, and the INPUT_PULLUP that replaced
    it was another, which is why the symptom survived the f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
    [main.cpp]
2026-08-20 Bring up the WiFi stack before using it, and stream the audio
    Four things in the network layer, all found by measuring a /look on the
    bench board rather than by reading.
    _trySTA() called WiFi.disconnect(true) before the stack had ever been
    brought up. That returns ESP_ERR_WIFI_NOT_INIT and leaves the driver
    somewhere the following begin() cannot recover from, which then reports
    ESP_ERR_WIFI_NOT_STARTED. The `true` also powers the radio down, so the
    retry from loop() came back to a stack that was off and failed the same
    way again: a board with perfectly good credentials printed "Wifi
    Reconnecting" for ever and never joined anything.
    Responses can now be consumed three ways instead of one. A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
2026-08-20 Speak the answer as it arrives instead of after it lands
    playWav() needs the whole file before it makes a sound, which for /look
    meant downloading a few hundred KB to the card and then reading them back
    before the first word: measured at 4848 ms of download plus 534 ms of
    re-reading, all of it before any audio. beginStream/writeStream/endStream
    take raw pcm16 off the socket instead and hand it to the amplifier as it
    lands.
    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
2026-08-20 Describe the scene on a button press, and a console to set the board up
    A single press now photographs what is in front of the wearer, sends it to
    /look and speaks the answer. Double press is unchanged.
    There was no way to configure a board at all before this. addNetwork()
    existed but nothing called it -- the BLE service that used to went with the
    audio rewrite and nothing replaced it, and there is no AP mode -- so a
    freshly flashed board sat printing "Wifi Reconnecting" with no way to be
    told a network. There is now a serial console: ssid/pass, lang, backend,
    scan, look, show, save, reboot. Each command takes the rest of the line
    verbatim, so SSIDs and passwords with spaces need no quoting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
    [main.cpp]
2026-08-21 Configure the board over WiFi instead of the serial console
    The serial console was the only way to configure a board, which means a
    board is only configurable next to a computer. It goes, and the access
    point that replaces it comes up in two situations with a page each:
    first boot no credentials on the card, so setup() raises the AP
    before the WiFi stack starts and serves the onboarding
    walkthrough.
    long press a board that already works. Two seconds on the button
    plays an 880 Hz tone and serves the panel: one screen,
    prefilled, for changing a password or a URL.
    The panel is a new page on the wizard's design system — same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
    [main.cpp]
2026-08-21 Send SVGA, the largest frame the backend does not shrink
    XGA was wrong. bonsai-backend's app/images.py resizes the long side to
    IMAGE_MAX_SIDE (896 px by default) and returns early only when
    max(width, height) <= 896, so 1024 gets shrunk — the resize this was
    supposed to avoid. Its own docs/BENCHMARKS.md prices that at 192 ms,
    paid on top of uploading pixels the server then throws away.
    SVGA's 800 px is the largest of the camera's sizes that fits under 896,
    so it goes to the vision model untouched. This tracks IMAGE_MAX_SIDE
    rather than the sensor: raise it if that ever moves.
    [main.cpp]
2026-08-22 Catch button edges in an interrupt, not by polling the loop
    The button logic was right and the pin was clean — GPIO4 is claimed by
    nothing else and the camera does not touch it. What was wrong is that
    loop() does not run often enough to sample it.
    wifi.loop() calls _tryAllNetworks(), which calls _trySTA() for each
    configured network, and _trySTA() blocks in a while/delay(100) wait for
    up to _timeoutPerNetwork (5 s). On a board that cannot reach its network
    that freezes loop() for half of every 10 s window, and a 150 ms tap
    landing in that half was never sampled at all. Two networks would freeze
    it outright.
    An interrupt on CHANGE now records edges into a small ring with their own
    timesta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
    [main.cpp]
2026-08-22 Give up on the WiFi instead of retrying into the void
    Three things, all the same outage.
    The reconnect no longer blocks. loop() ran a whole sweep synchronously —
    _trySTA() sat in a while/delay(100) for up to five seconds per network —
    and the Arduino loop is what polls the button, so a press took five
    seconds to register. It is a three-state machine now: loop() advances it
    and returns. begin() stays blocking on purpose, since at boot there is
    nothing else to do and the board should get its best shot before setup()
    reaches anything that needs the network.
    It also stops fighting itself. A settle step between disconnect() and the
    next begin() lets the driver leave "sta is connecting", whi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
    [main.cpp]
2026-08-22 Say "no wifi" once, from the one place that means it
    Three faults, one story: the board said it had no network twice and then
    carried on trying anyway.
    look() never reached the guard in _request(). It has its own isConnected()
    check that played the clip and returned, so the offline path never ran,
    the panel never came up, and pressing the button did nothing to stop the
    reconnect. It now raises the same flag as everything else and lets loop()
    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
2026-08-22 Stop the station fighting the access point for the radio
    The panel's AP did not show up in the phone's list. Keeping the station
    attached in panel mode was mine, and the reasoning behind it was wrong:
    the comment claimed the board is already on the user's network, which is
    the one thing that is not true when the panel comes up — it comes up
    because the retries just ran out.
    A station that is still trying keeps the radio scanning off-channel for a
    network that is not there. The AP's beacons go out only in the gaps, and
    the phone never lists it. A station that is genuinely associated is worth
    keeping, because that is what lets /api/test reach the backend instead of
    answering "ap_mode". So t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
2026-08-22 Drop the Groq key, and make a failed association say why
    The key never belonged on the device. app/vision.py reads it from
    GROQ_API_KEY in the backend's own environment and never from the request,
    so what the board collected, stored and sent was dead weight — and a
    secret sitting on an SD card for nothing. Gone from both pages, from the
    GET and POST handlers, and from the endpoint docs, which also claimed
    /api/test took it when the implementation never read it. Boards that ran
    an older build have theirs dropped from /config.json on the next boot.
    The rest is instrumentation for "it sees the network but will not join
    it", which until now was a five second silence followed by "Wifi
    Reconnec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
    [main.cpp]
2026-08-22 Wait for the disconnect the driver reports, not for a guess
    Cycling WIFI_OFF/WIFI_STA before each attempt was my fix for
    ESP_ERR_WIFI_STATE and it traded one fault for another: WIFI_OFF stops the
    driver, so begin() then landed on a stack that had not finished starting
    and the log filled with ESP_ERR_WIFI_NOT_STARTED — the exact failure the
    comment in _trySTA warns about, walked into from the other side.
    The signal was already there. The event handler added for reason codes
    also marks the station settled, so Settling now waits for the disconnect
    to actually happen rather than for 400 ms, or for a mode cycle, or for
    anything else inferred. The driver is never stopped. kSettleMaxMs is only
    a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
    [main.cpp]
2026-08-22 Take the retry policy off the framework, it was fighting us
    The password is right and the AP is 2.4 GHz, which makes the whole reason-2
    story wrong. The log said so: begin() was returning ESP_ERR_WIFI_STATE from
    esp_wifi_set_config(), meaning the credentials were never applied, so the
    disconnects that followed were the driver retrying the *previous* config.
    A network that was not even in range reported a password error — that was
    the tell.
    STA.cpp reconnects on its own from inside the disconnect handler,
    disconnect() then connect(), for any reason it deems retryable, and
    AUTH_EXPIRE is one. So every attempt landed on a station the framework had
    already put back into "connecting", and noth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
2026-08-22 Say when the signal is the problem, since it was
    The scan line reported channel, security and dBm, and the sentence under it
    pointed at the two causes it was not: channel above 11, or WPA3. The board
    in front of us reads channel 1, WPA/WPA2 and -90 dBm, and -90 is the whole
    answer.
    Beacons go out slowly and robustly, so an AP keeps showing up in scans long
    after associating with it has become impossible — the reply from this end
    never lands and the authentication expires. That is a reason 2 with a
    perfectly correct password. The line now grades the signal and says so.
2026-08-22 Collect two seconds before speaking, not one
    kPrebufferMs is the one knob that trades latency for not stuttering, and it
    goes to 2000. Two other numbers had to move with it or the setting would
    have been decorative.
    kPrebufferTimeoutMs was 2500. Sixty-four kilobytes — what two seconds at
    16 kHz comes to — takes 2.1 to 3.1 seconds over the 21-30 KB/s this link
    measures, so the wait would have given up short of its target about half
    the time and started early. 6000 leaves room to actually reach it.
    The ring was 64 KB, which is exactly the new prebuffer at 16 kHz. A buffer
    no bigger than the amount it collects before starting blocks the socket
    reader the instant playback begins, so it dou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
2026-08-22 Stop making the answer wait: 400 ms of prebuffer, warm TLS at boot
    The last commit read "make the audio take 2s" as a prebuffer setting and
    raised it. The ask was the opposite — get the answer out in about two
    seconds instead of seven — so that goes back and further.
    kPrebufferMs is 400, down from the 1000 it was before I touched it. Safe,
    and now for a stated reason rather than a guess: _look() asks for 8 kHz
    when streaming, which consumes 16 KB/s against the 21-30 KB/s this link
    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
2026-08-22 Feed the DMA silence when the network is late, not nothing
    Reported symptom: the first or second word sometimes clips or repeats. The
    repeat is the mechanism showing through. The TX DMA is circular, so
    starving it makes the hardware send its last buffer again — and again —
    which is heard as the previous fragment stuttering. The player was doing
    exactly that: on an empty ring it counted an underrun and continued
    without writing anything.
    It now writes a stage of zeros instead. A hole in the network is rendered
    as a short gap, which is honest and far less objectionable than a word
    repeating. The receive timeout drops from 100 ms to 20 ms as well, since
    that value is how long the DMA is le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
2026-08-22 Take the camera tuning from the live web preview
    Someone sat in front of the sensor's own web server and tuned it, so those
    values win over the driver's defaults. Applied: AWB on with advanced and
    manual AWB off, AEC, AGC, GMA, lens correction, black and white pixel
    correction, no special effect, no colour bar, vflip on and hmirror off.
    Most of these the sensor already did; setting them explicitly means the
    picture no longer depends on what the driver happened to leave behind.
    Saturation goes -2 to +3 and brightness 0 to +1, and both reverse notes
    that were recorded from measurements rather than guesses. The saturation
    note said stock colours were overcooked. The brightness note said +1 cli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
2026-08-30 Flash a board from a web page, no toolchain needed
    Getting firmware onto a board meant installing PlatformIO and building it
    locally, which is a lot to ask of anyone who just wants a working device.
    This adds a GitHub Pages site under docs/ that reads the repository's
    releases through the GitHub API and writes one to a connected board over
    the Web Serial API, using a vendored esptool-js. The binaries go from
    GitHub to the serial port inside the browser; nothing is uploaded.
    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
2026-08-30 Wear the setup page's clothes, and publish the builds it flashes
    Three things were wrong with the flasher.
    It warned that a full erase would wipe /config.json. It would not:
    config.json, the saved networks and the voice clips live on the SD card,
    and nothing on this page touches the card. The option is gone rather than
    relabelled, since erasing the flash was never something the page needed
    to offer, and the footer now says settings survive a flash.
    It also invented its own look, a dark console, while the firmware already
    onboards people through bonsai-setup.html. The page now takes that file's
    tokens and components verbatim: the same ground, logo, step rail, buttons,
    summary rows and statu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
2026-08-30 Say who has to switch Pages on, since the token cannot
    The enablement flag looked like it would save that step, but the run
    comes back "Create Pages site failed: Resource not accessible by
    integration": the workflow token may deploy to Pages, not create the
    site. The flag is gone and both the workflow and docs/README.md now say
    where the setting is and what the failure looks like until it is on.
    Claude-Session: https://claude.ai/code/session_018YAqUpc64zHcuQyY5bDxnS
2026-09-23 Let the sensor apply the white balance it works out
    Photos came out magenta. set_whitebal only lets the OV3660 decide a white
    balance; set_awb_gain is what applies the resulting R/B channel gains. With
    the gain off the sensor measured the cast and left it in the frame.
    Both values came from the last commit, read off slider positions in a
    screenshot of the web panel and accurate, by that commit's own admission, only
    to within a step. A switch read the wrong way round is exactly this bug, so
    awb_gain goes back to the driver default of 1.
    Saturation to neutral at the same time. It cannot create a cast but it
    multiplies one, and 0 keeps it out of the way while the cast is being chased.
    If the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
2026-09-23 Take the sharpest of three frames and stop veiling the photo
    Brightness back to 0 after a lamp in shot washed the frame grey, sharpness
    +2 for the fixed-focus lens, gain capped at 8x, and capture() keeps the
    largest JPEG of a three-frame burst.
2026-09-23 Record the question on its own task and hear it reliably
    The "tell me" clip now starts on the button press, with the capture and the
    photo upload underneath it. The mic opens the moment the clip ends and queues
    voiced audio in PSRAM until the request takes it, so a slow upload no longer
    swallows the first words.
    VoiceGate measures a pre-emphasised level, tracks the noise floor with minimum
    statistics instead of averaging the first 250 ms (which measured the speaker's
    own voice as the room), and also ends on silence relative to the speaker's
    level. "mic_debug": true prints the numbers for tuning.
    Also carries the pending Audio, WiFiManager, /ask streaming and latency notes.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
    [main.cpp]
